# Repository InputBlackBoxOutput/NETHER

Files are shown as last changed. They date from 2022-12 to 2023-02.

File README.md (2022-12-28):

# NETHER
Virtual reality controller for playing minecraft

## Salient features
* Modular to support addons
* Tangle free gaming since the entire system is wireless
* Minimal lag during gaming due to high-speed data transfer
* Product certifications: CE certified and ROHS compliant 

## System block diagram
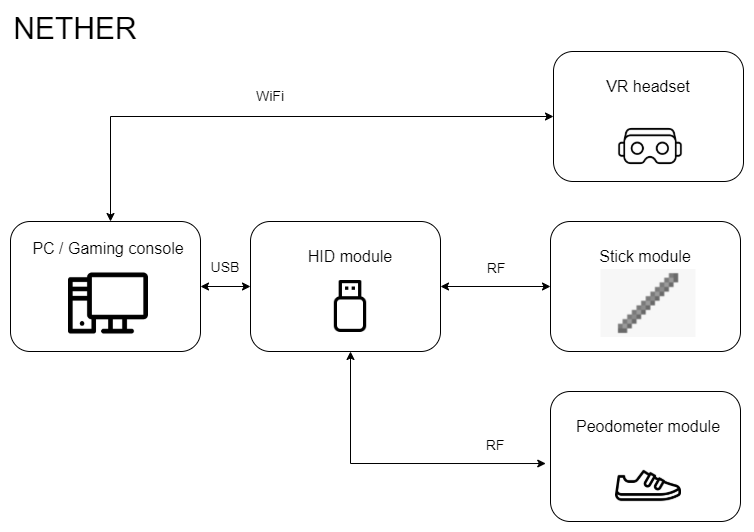
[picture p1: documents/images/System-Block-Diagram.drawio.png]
System block diagram


## HID module

### Functions 
- Act as a wireless gateway between the modules worn by the user and the computer.
- Communicate with the computer via USB as an HID device

### 3D render: Exploded view
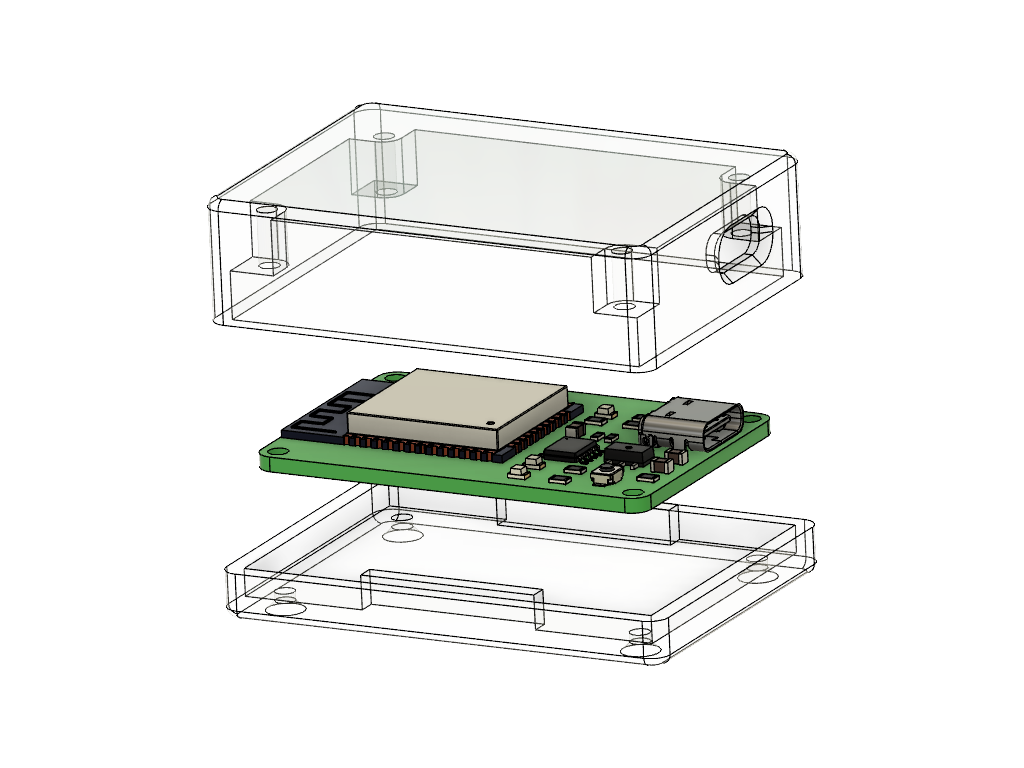
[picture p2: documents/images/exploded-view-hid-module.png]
3D render: Exploded view


## Stick module

### Functions
- Connect with the HID module wirelessly
- Send data associated with a button when a button is pressed
- Read IMU data, detect striking movement and send the data to the HID module
- Calibrate the IMU device when the calibration button is pressed

### 3D render: Exploded view
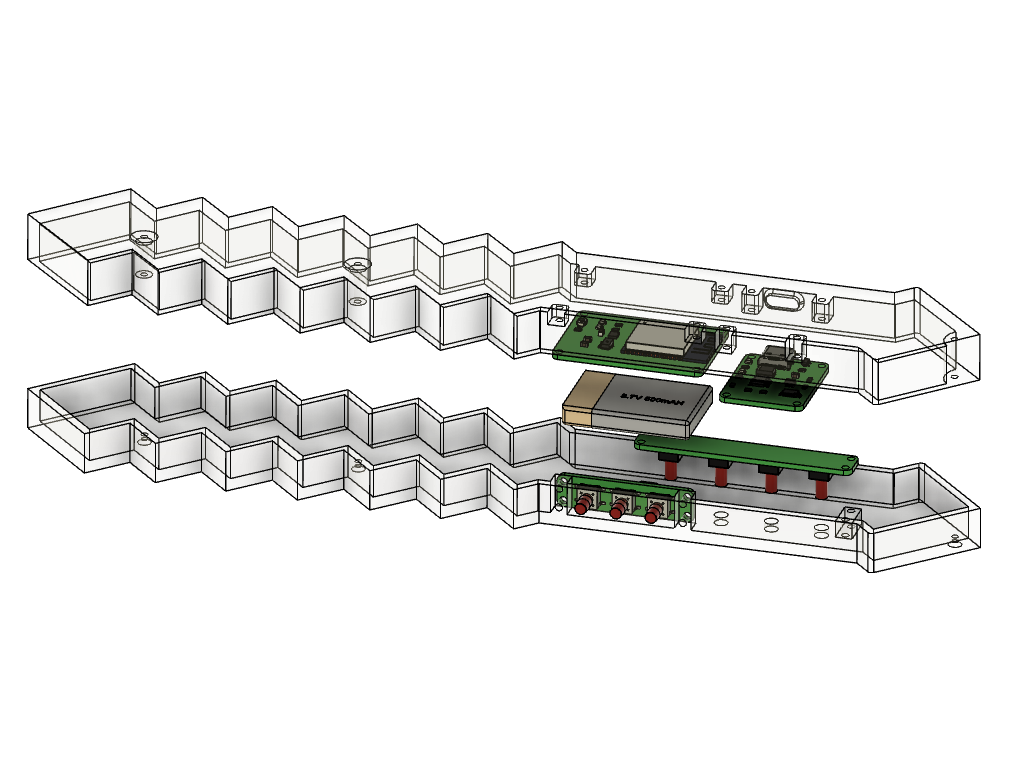
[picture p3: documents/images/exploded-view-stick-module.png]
3D render: Exploded view


## Pedometer module

### Functions
- Connect with the HID module wirelessly
- Read accelerometer data, detect steps and send the data to the HID module
- Calibrate the IMU device when the calibration button is pressed

### 3D render: Exploded view
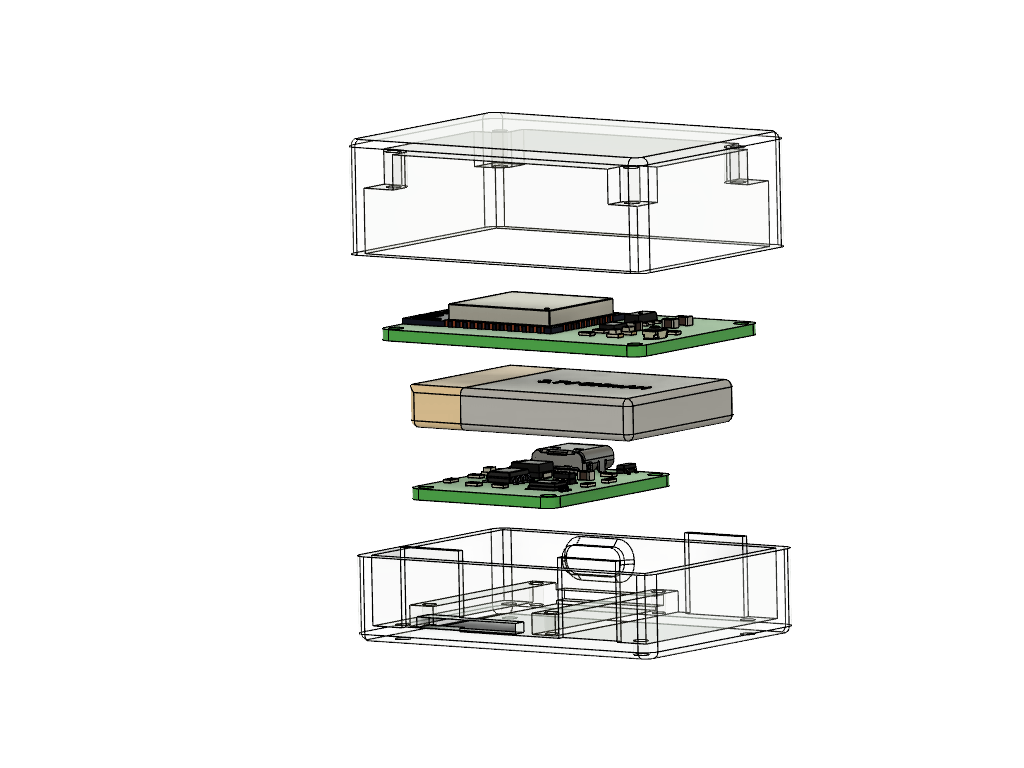
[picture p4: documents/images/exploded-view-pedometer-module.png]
3D render: Exploded view

  
### Made with lots of ⏱️, 📚 and ☕ by InputBlackBoxOutput

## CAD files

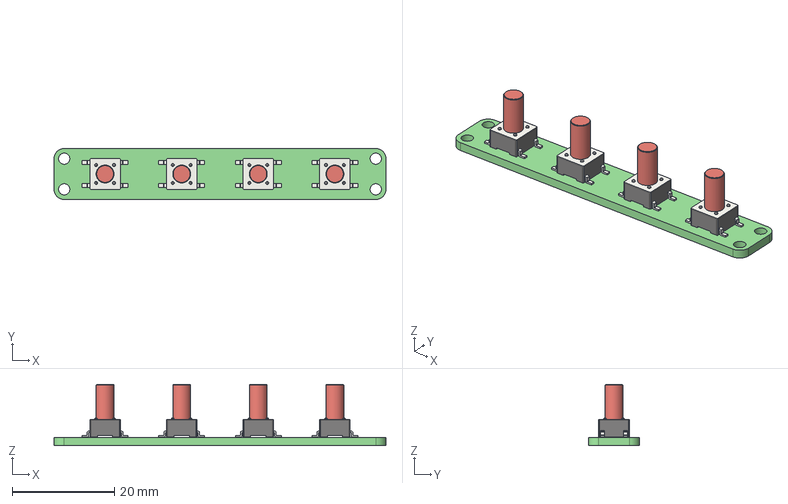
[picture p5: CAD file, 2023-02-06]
modules/Stick module/button-board-1/board.step
65.0 x 10.0 x 12.0 mm

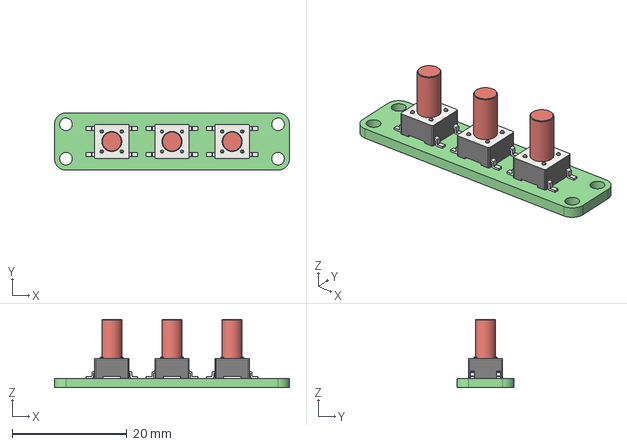
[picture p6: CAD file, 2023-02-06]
modules/Stick module/button-board-2/board.step
41.0 x 10.0 x 12.0 mm

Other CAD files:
modules/HID module/enclosure/Enclosure.f3d
modules/Pedometer module/enclosure/Enclosure.f3d
modules/Stick module/enclosure/Enclosure.f3z

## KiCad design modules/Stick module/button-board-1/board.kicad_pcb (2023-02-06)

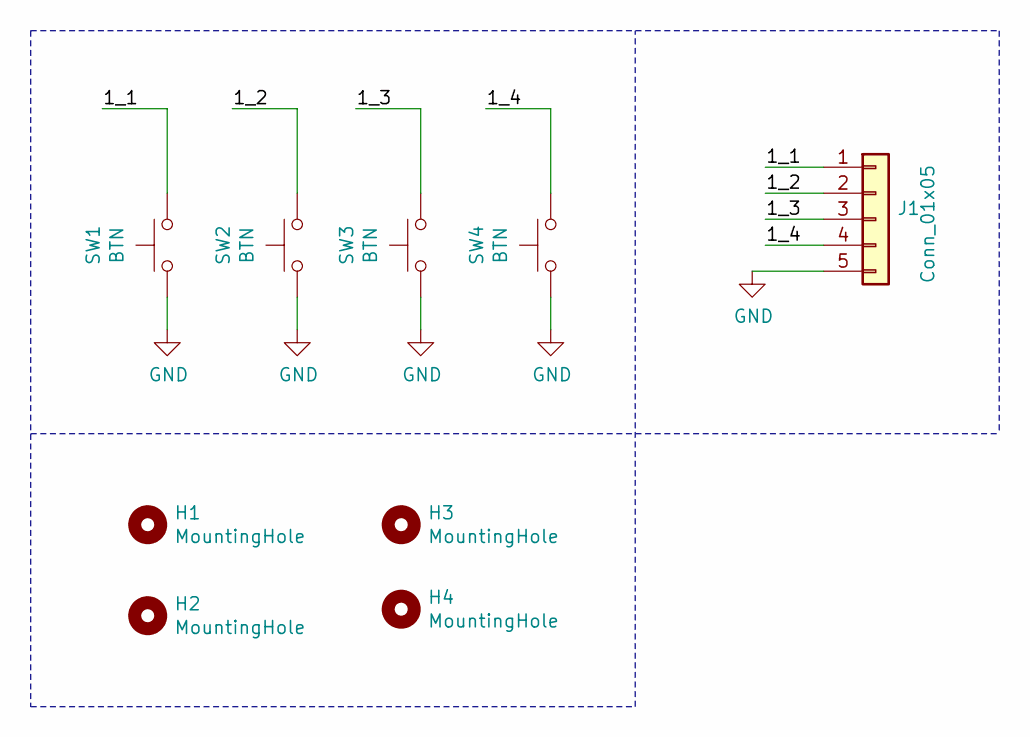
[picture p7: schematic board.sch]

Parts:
H1, H2, H3, H4: MountingHole; MountingHole_2.2mm_M2
J1: Conn_01x05; SolderWire_1x05_P2.54mm
SW1, SW2, SW3, SW4: BTN; SW_SPST_Omron_B3FS-100xP

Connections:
/1_1: J1.1, SW1.2
/1_2: J1.2, SW2.2
/1_3: J1.3, SW3.2
/1_4: J1.4, SW4.2
GND: J1.5, SW1.1, SW2.1, SW3.1, SW4.1

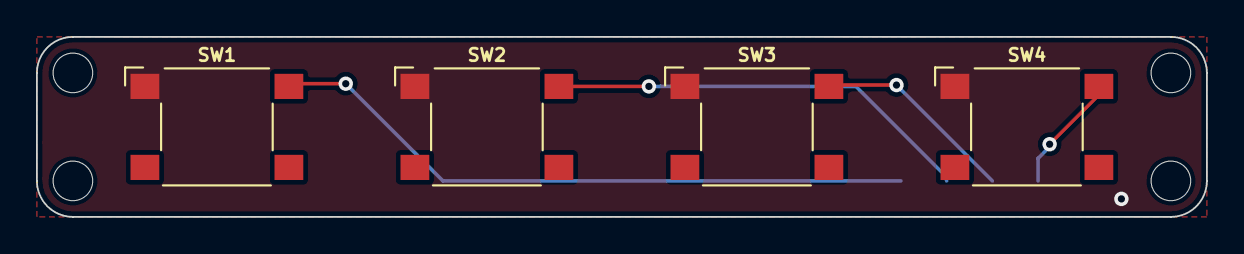
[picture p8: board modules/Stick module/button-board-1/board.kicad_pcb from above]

Board: 2 copper layers, 65.0 x 10.0 mm, 9 parts (1 on the bottom side), 5 nets.

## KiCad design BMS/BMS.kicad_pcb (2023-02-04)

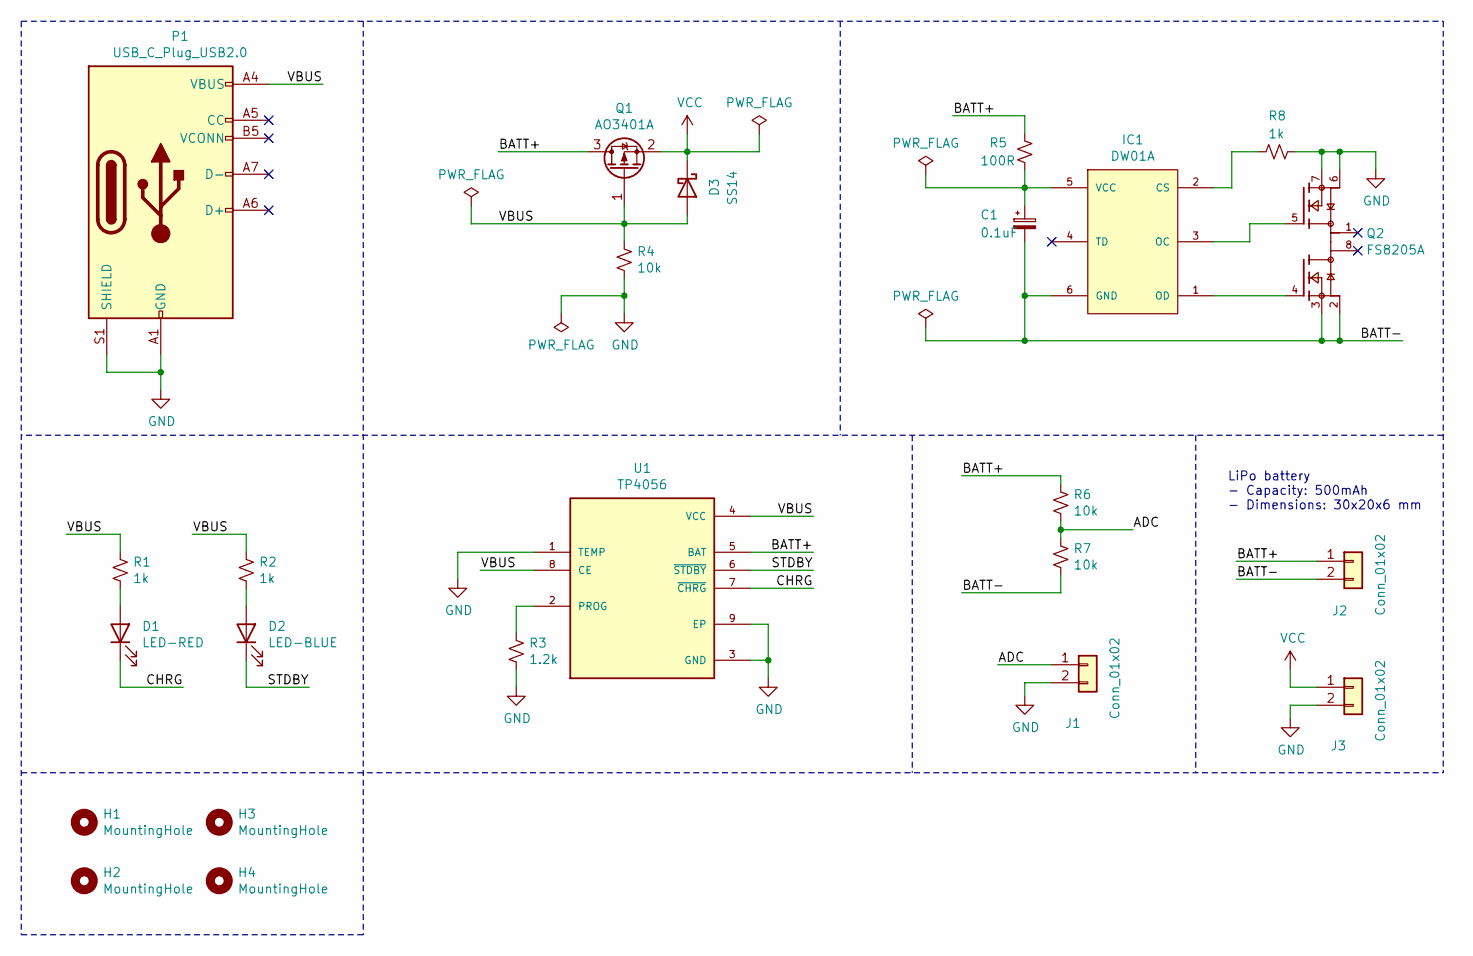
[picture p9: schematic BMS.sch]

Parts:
C1: 0.1uF; C_0805_2012Metric_Pad1.18x1.45mm_HandSolder
D1: LED-RED; LED_0805_2012Metric_Pad1.15x1.40mm_HandSolder
D2: LED-BLUE; LED_0805_2012Metric_Pad1.15x1.40mm_HandSolder
D3: SS14; D_SMB
H1, H2, H3, H4: MountingHole; MountingHole_2.2mm_M2
IC1: DW01A; SOT-23-6_Handsoldering; MPN DW01A; LCSC C351410
J1, J2, J3: Conn_01x02; Wire-Pad-01x02
P1: USB_C_Plug_USB2.0; USB_C_Receptacle_HRO_TYPE-C-31-M-12
Q1: AO3401A; SOT-23
Q2: FS8205A; SOP65P640X120-8N; PARTREV 1.7
R1, R2, R8: 1k; R_0805_2012Metric_Pad1.20x1.40mm_HandSolder
R3: 1.2k; R_0805_2012Metric_Pad1.20x1.40mm_HandSolder
R4, R6, R7: 10k; R_0805_2012Metric_Pad1.20x1.40mm_HandSolder
R5: 100R; R_0805_2012Metric_Pad1.20x1.40mm_HandSolder
U1: TP4056; SOP127P600X175-9N

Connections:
/ADC: J1.1, R6.2, R7.1
/BATT+: J2.1, Q1.3 (D), R5.1, R6.1, U1.5 (BAT)
/BATT-: C1.2, IC1.6 (GND), J2.2, Q2.2, Q2.3, R7.2
/CHRG: D1.1 (K), U1.7 (~CHRG)
/STDBY: D2.1 (K), U1.6 (~STDBY)
/VBUS: D3.2 (A), P1.A4 (VBUS), P1.A9 (VBUS), P1.B4 (VBUS), P1.B9 (VBUS), Q1.1 (G), R1.1, R2.1, R4.1, U1.4 (VCC), U1.8 (CE)
GND: J1.2, J3.2, P1.A1 (GND), P1.A12 (GND), P1.B1 (GND), P1.B12 (GND), P1.S1 (SHIELD), Q2.6, Q2.7, R3.2, R4.2, R8.1, U1.1 (TEMP), U1.3 (GND), U1.9 (EP)
unnamed: C1.1, IC1.5 (VCC), R5.2
unnamed: D1.2 (A), R1.2
unnamed: D2.2 (A), R2.2
unnamed: IC1.1 (OD), Q2.4
unnamed: IC1.2 (CS), R8.2
unnamed: IC1.3 (OC), Q2.5
unnamed: R3.1, U1.2 (PROG)
VCC: D3.1 (K), J3.1, Q1.2 (S)

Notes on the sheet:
LiPo battery - Capacity: 500mAh - Dimensions: 30x20x6 mm

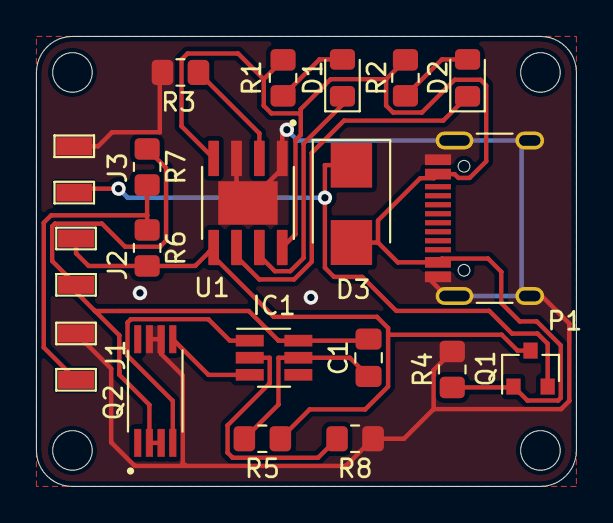
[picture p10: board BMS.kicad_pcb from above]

Board: 2 copper layers, 30.0 x 25.0 mm, 24 parts (0 on the bottom side), 15 nets.

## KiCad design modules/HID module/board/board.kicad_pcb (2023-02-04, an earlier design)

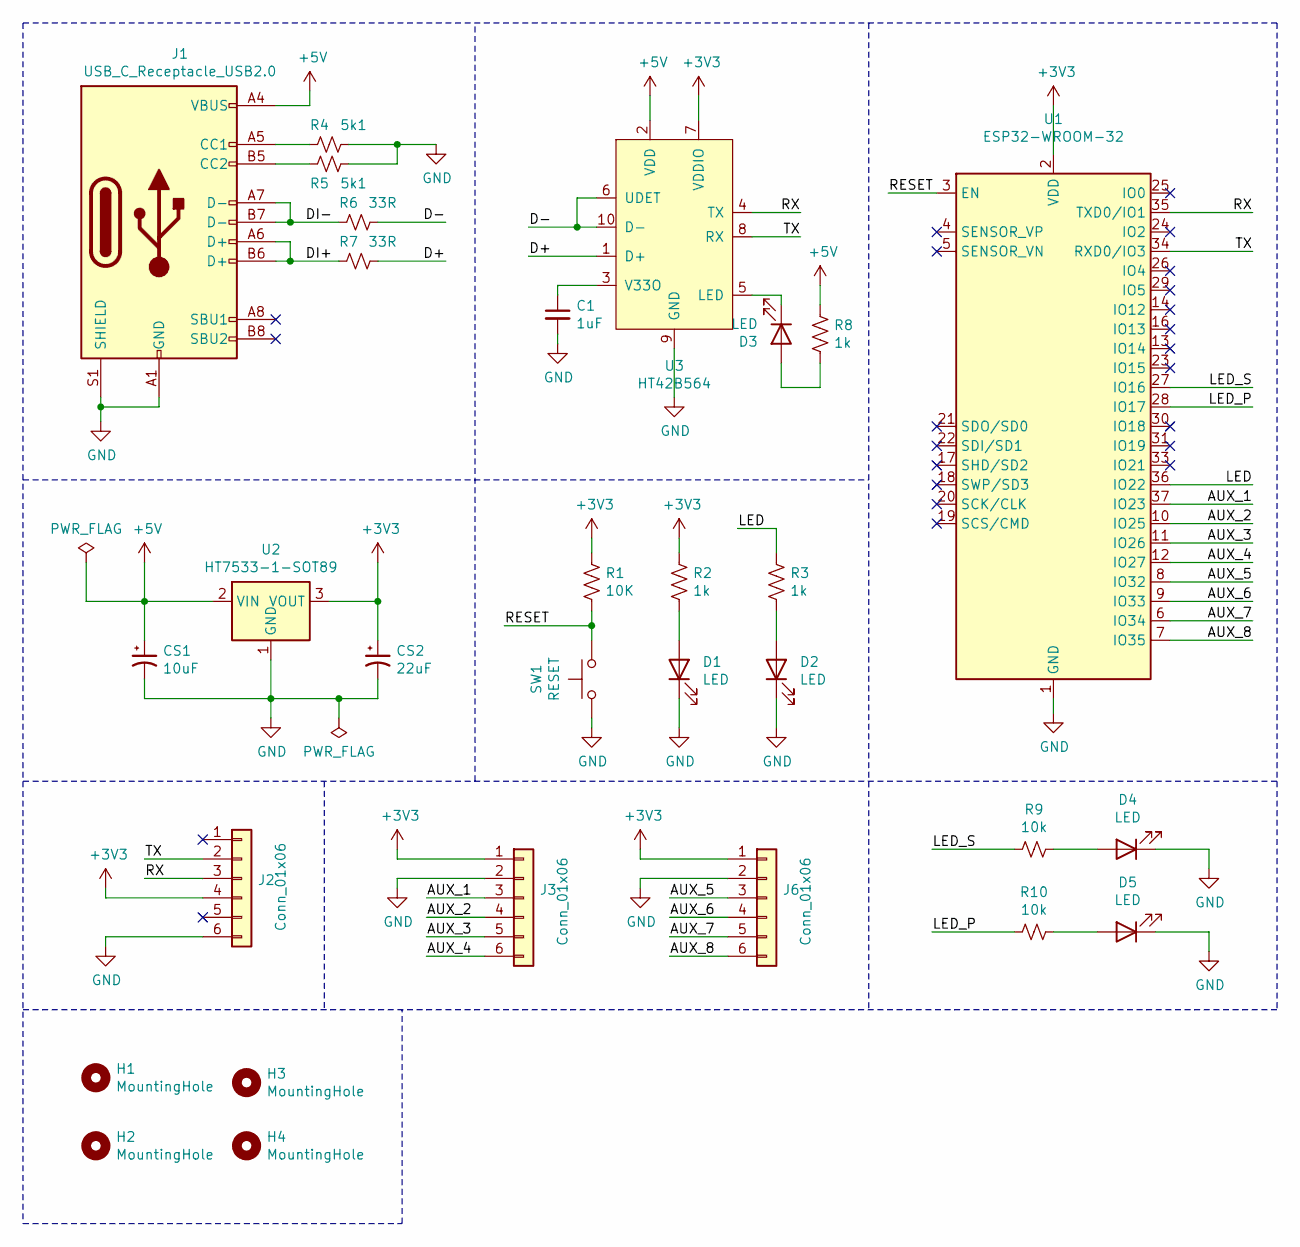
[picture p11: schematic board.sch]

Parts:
C1: 1uF; C_0805_2012Metric_Pad1.18x1.45mm_HandSolder
CS1: 10uF; C_0805_2012Metric_Pad1.18x1.45mm_HandSolder
CS2: 22uF; C_0805_2012Metric_Pad1.18x1.45mm_HandSolder
D1, D2, D3, D4, D5: LED; LED_0805_2012Metric_Pad1.15x1.40mm_HandSolder
H1, H2, H3, H4: MountingHole; MountingHole_2.2mm_M2
J1: USB_C_Receptacle_USB2.0; USB_C_Receptacle_HRO_TYPE-C-31-M-12
J2, J3, J6: Conn_01x06; SolderWire_1x06_P2.54mm
R1: 10K; R_0805_2012Metric_Pad1.20x1.40mm_HandSolder
R2, R3, R8: 1k; R_0805_2012Metric_Pad1.20x1.40mm_HandSolder
R4, R5: 5k1; R_0805_2012Metric_Pad1.20x1.40mm_HandSolder
R6, R7: 33R; R_0603_1608Metric_Pad0.98x0.95mm_HandSolder
R9, R10: 10k; R_0805_2012Metric_Pad1.20x1.40mm_HandSolder
SW1: RESET; SW_SPST_B3U-1000P
U1: ESP32-WROOM-32
U2: HT7533-1-SOT89; SOT-89-3
U3: HT42B564; SSOP-10_3.9x4.9mm_P1.00mm

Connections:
+3V3: CS2.1, J2.4, J3.1, J6.1, R1.1, R2.1, U1.2 (VDD), U2.3 (VOUT), U3.7 (VDDIO)
+5V: CS1.1, J1.A4 (VBUS), J1.A9 (VBUS), J1.B4 (VBUS), J1.B9 (VBUS), R8.1, U2.2 (VIN), U3.2 (VDD)
/AUX_1: J3.3, U1.37 (IO23)
/AUX_2: J3.4, U1.10 (IO25)
/AUX_3: J3.5, U1.11 (IO26)
/AUX_4: J3.6, U1.12 (IO27)
/AUX_5: J6.3, U1.8 (IO32)
/AUX_6: J6.4, U1.9 (IO33)
/AUX_7: J6.5, U1.6 (IO34)
/AUX_8: J6.6, U1.7 (IO35)
/D+: R7.1, U3.1 (D+)
/D-: R6.1, U3.6 (UDET), U3.10 (D-)
/DI+: J1.A6 (D+), J1.B6 (D+), R7.2
/DI-: J1.A7 (D-), J1.B7 (D-), R6.2
/LED: R3.1, U1.36 (IO22)
/LED_P: R10.2, U1.28 (IO17)
/LED_S: R9.2, U1.27 (IO16)
/RESET: R1.2, SW1.2, U1.3 (EN)
/RX: J2.3, U1.35 (TXD0/IO1), U3.4 (TX)
/TX: J2.2, U1.34 (RXD0/IO3), U3.8 (RX)
GND: C1.2, CS1.2, CS2.2, D1.1 (K), D2.1 (K), D4.1 (K), D5.1 (K), J1.A1 (GND), J1.A12 (GND), J1.B1 (GND), J1.B12 (GND), J1.S1 (SHIELD), J2.6, J3.2, J6.2, R4.1, R5.1, SW1.1, U1.1 (GND), U1.15 (GND), U1.38 (GND), U1.39 (GND), U2.1 (GND), U3.9 (GND)
unnamed: C1.1, U3.3 (V33O)
unnamed: D1.2 (A), R2.2
unnamed: D2.2 (A), R3.2
unnamed: D3.1 (K), U3.5 (LED)
unnamed: D3.2 (A), R8.2
unnamed: D4.2 (A), R9.1
unnamed: D5.2 (A), R10.1
unnamed: J1.A5 (CC1), R4.2
unnamed: J1.B5 (CC2), R5.2

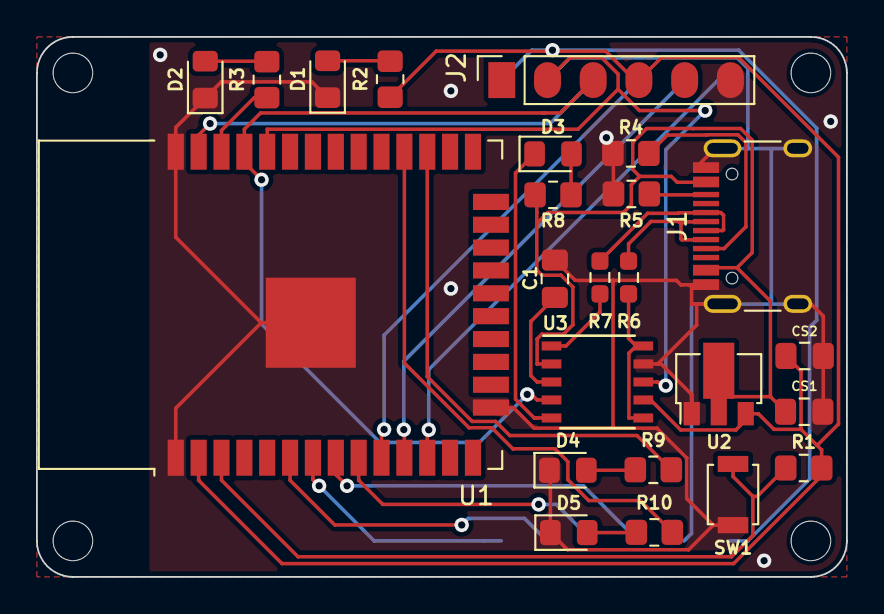
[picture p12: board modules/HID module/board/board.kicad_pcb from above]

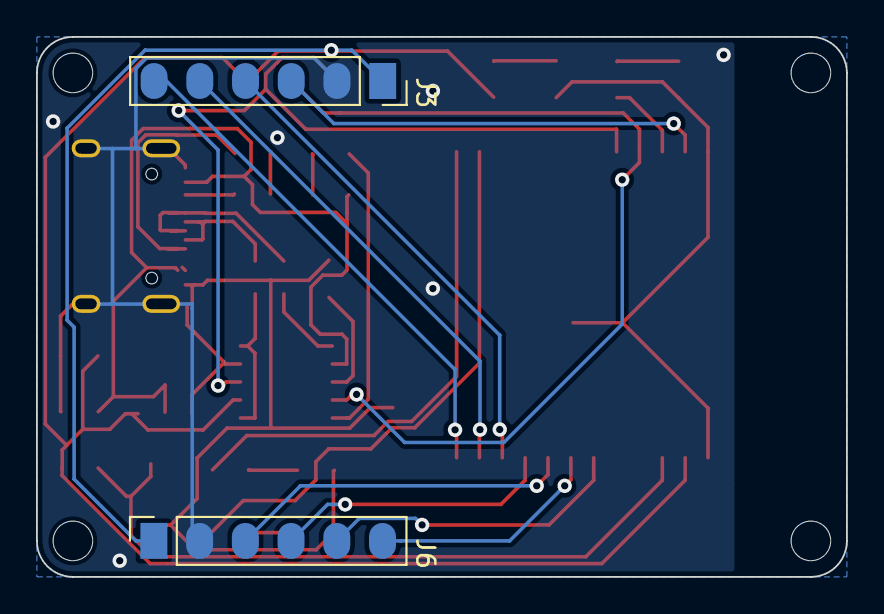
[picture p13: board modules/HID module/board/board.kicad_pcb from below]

Board: 2 copper layers, 45.0 x 30.0 mm, 30 parts (2 on the bottom side), 30 nets.

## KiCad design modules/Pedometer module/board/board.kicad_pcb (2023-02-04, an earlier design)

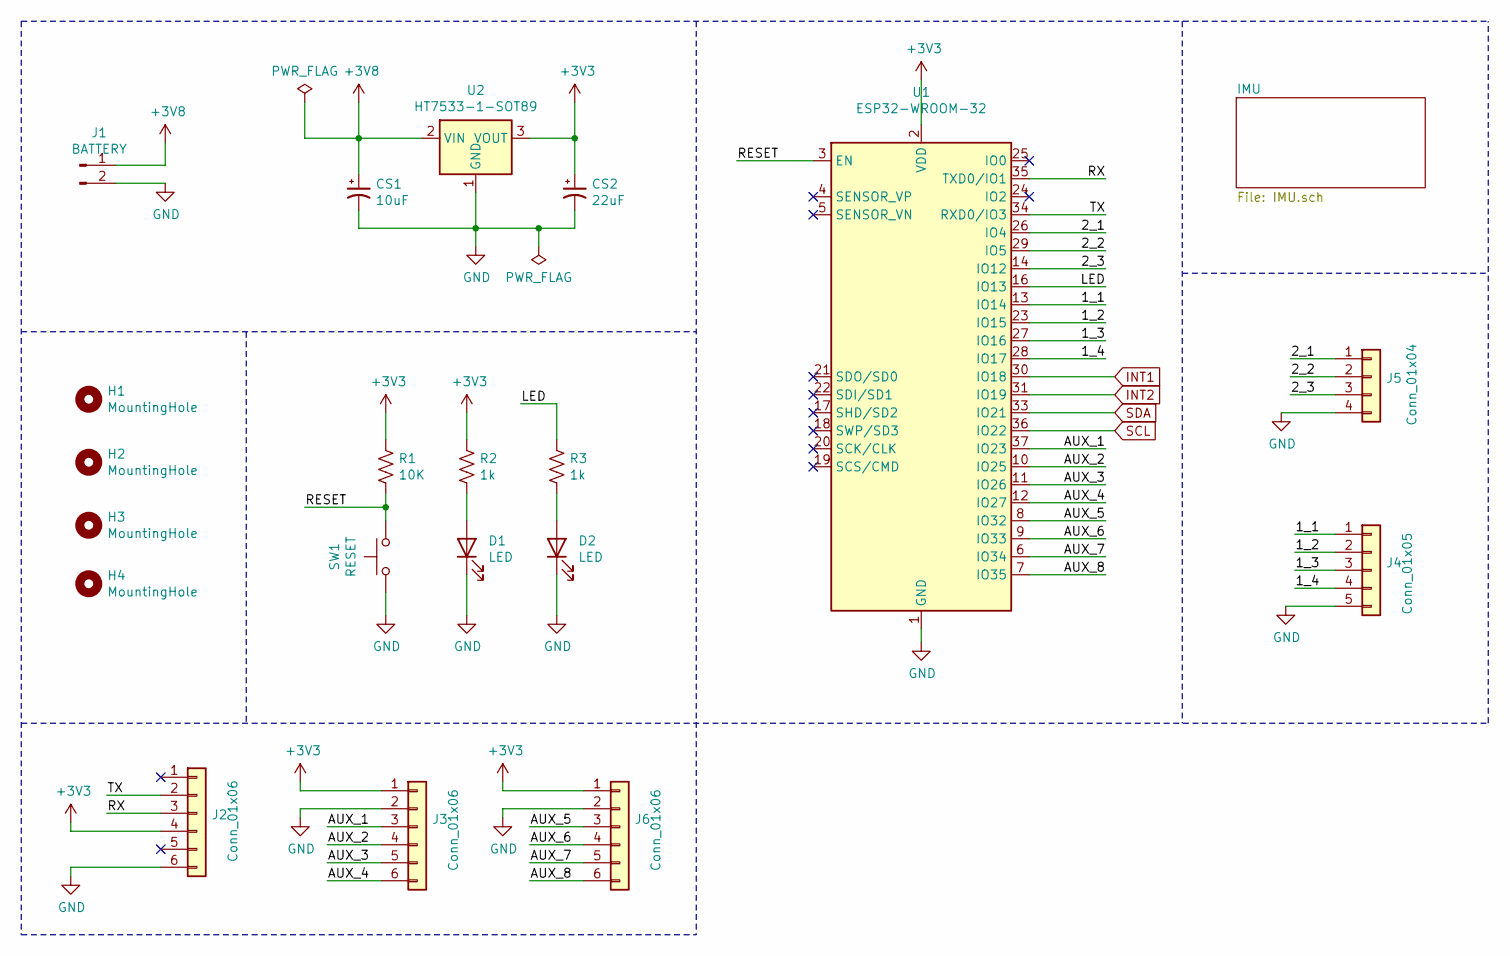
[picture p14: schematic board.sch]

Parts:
CS1: 10uF; C_0805_2012Metric_Pad1.18x1.45mm_HandSolder
CS2: 22uF; C_0805_2012Metric_Pad1.18x1.45mm_HandSolder
D1, D2: LED; LED_0805_2012Metric_Pad1.15x1.40mm_HandSolder
H1, H2, H3, H4: MountingHole; MountingHole_2.2mm_M2
J1: BATTERY; SolderWire_1x02_P2.00mm
J2, J3, J6: Conn_01x06; SolderWire_1x06_P2.54mm
J4: Conn_01x05; SolderWire_1x05_P2.54mm
J5: Conn_01x04; SolderWire_1x04_P2.54mm
R1: 10K; R_0805_2012Metric_Pad1.20x1.40mm_HandSolder
R2, R3: 1k; R_0805_2012Metric_Pad1.20x1.40mm_HandSolder
SW1: RESET; SW_SPST_B3U-1000P
U1: ESP32-WROOM-32
U2: HT7533-1-SOT89; SOT-89-3

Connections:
+3V3: CS2.1, J2.4, J3.1, J6.1, R1.1, R2.1, U1.2 (VDD), U2.3 (VOUT); also elsewhere on the board
+3V8: CS1.1, J1.1, U2.2 (VIN)
/1_1: J4.1, U1.13 (IO14)
/1_2: J4.2, U1.23 (IO15)
/1_3: J4.3, U1.27 (IO16)
/1_4: J4.4, U1.28 (IO17)
/2_1: J5.1, U1.26 (IO4)
/2_2: J5.2, U1.29 (IO5)
/2_3: J5.3, U1.14 (IO12)
/AUX_1: J3.3, U1.37 (IO23)
/AUX_2: J3.4, U1.10 (IO25)
/AUX_3: J3.5, U1.11 (IO26)
/AUX_4: J3.6, U1.12 (IO27)
/AUX_5: J6.3, U1.8 (IO32)
/AUX_6: J6.4, U1.9 (IO33)
/AUX_7: J6.5, U1.6 (IO34)
/AUX_8: J6.6, U1.7 (IO35)
/LED: R3.1, U1.16 (IO13)
/RESET: R1.2, SW1.2, U1.3 (EN)
/RX: J2.3, U1.35 (TXD0/IO1)
/TX: J2.2, U1.34 (RXD0/IO3)
GND: CS1.2, CS2.2, D1.1 (K), D2.1 (K), J1.2, J2.6, J3.2, J4.5, J5.4, J6.2, SW1.1, U1.1 (GND), U1.15 (GND), U1.38 (GND), U1.39 (GND), U2.1 (GND); also elsewhere on the board
INT1: U1.30 (IO18); also elsewhere on the board
INT2: U1.31 (IO19); also elsewhere on the board
unnamed: D1.2 (A), R2.2
unnamed: D2.2 (A), R3.2
SCL: U1.36 (IO22); also elsewhere on the board
SDA: U1.33 (IO21); also elsewhere on the board

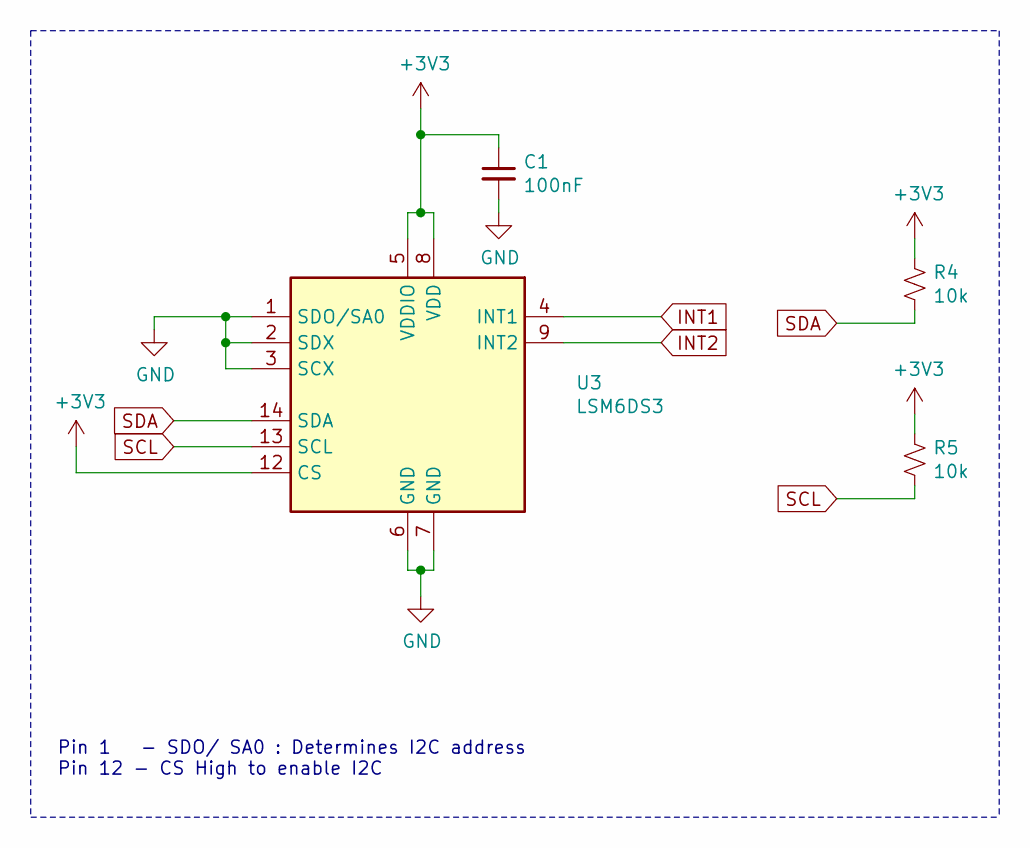
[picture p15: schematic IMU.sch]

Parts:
C1: 100nF; C_0805_2012Metric_Pad1.18x1.45mm_HandSolder
R4, R5: 10k; R_0805_2012Metric_Pad1.20x1.40mm_HandSolder
U3: LSM6DS3; LGA-14_3x2.5mm_P0.5mm_LayoutBorder3x4y

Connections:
+3V3: C1.1, R4.1, R5.1, U3.5 (VDDIO), U3.8 (VDD), U3.12 (CS); also elsewhere on the board
GND: C1.2, U3.1 (SDO/SA0), U3.2 (SDX), U3.3 (SCX), U3.6 (GND), U3.7 (GND); also elsewhere on the board
INT1: U3.4 (INT1); also elsewhere on the board
INT2: U3.9 (INT2); also elsewhere on the board
SCL: R5.2, U3.13 (SCL); also elsewhere on the board
SDA: R4.2, U3.14 (SDA); also elsewhere on the board

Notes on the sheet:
Pin 1 - SDO/ SA0 : Determines I2C address Pin 12 - CS High to enable I2C

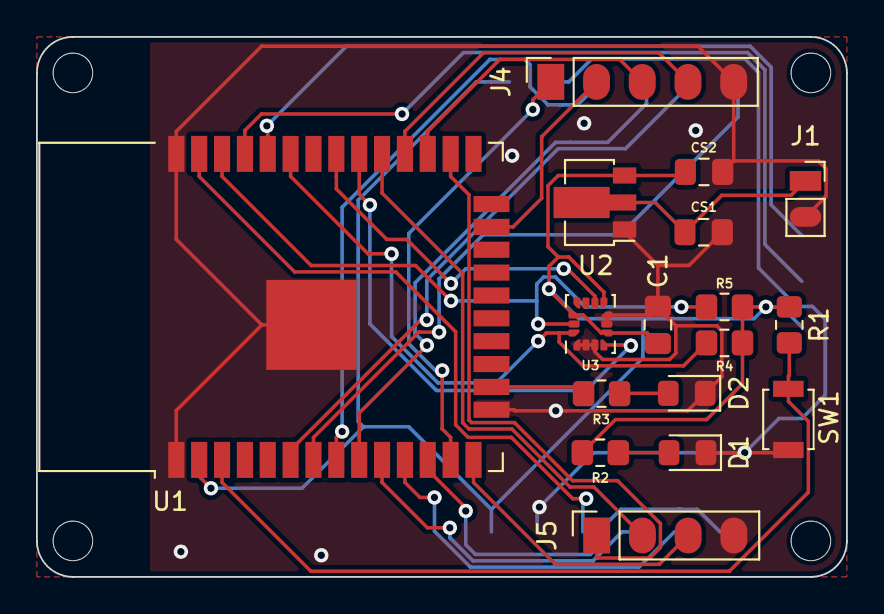
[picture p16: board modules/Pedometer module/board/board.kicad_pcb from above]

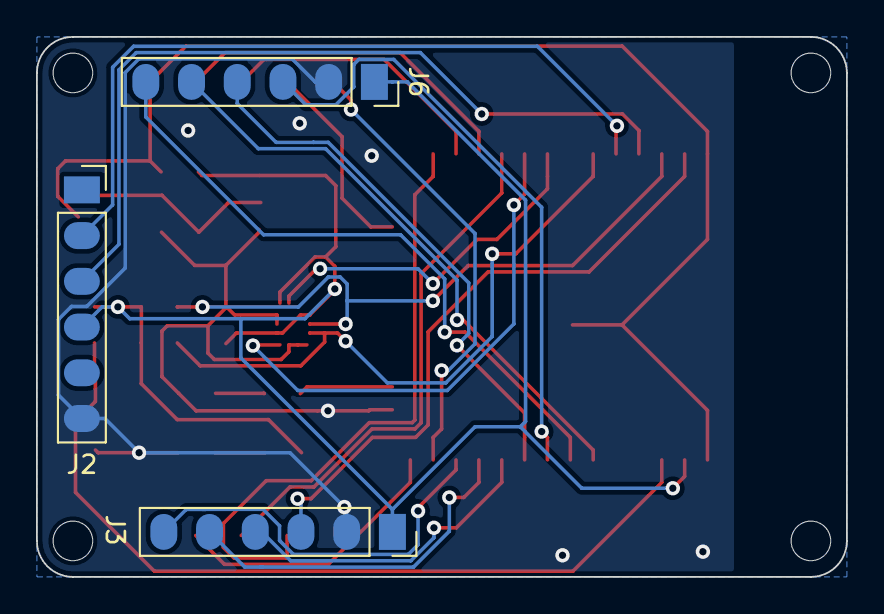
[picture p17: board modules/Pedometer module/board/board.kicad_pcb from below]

Board: 2 copper layers, 45.0 x 30.0 mm, 24 parts (3 on the bottom side), 28 nets.

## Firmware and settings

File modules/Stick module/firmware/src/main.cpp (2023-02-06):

// Stick module firmware
//
// TODO:
// TinyML based action classifier: Strike & Place
// Use buttons to implement other in-game actions
//
// References:
// https://randomnerdtutorials.com/esp-now-many-to-one-esp32/
// https://randomnerdtutorials.com/get-change-esp32-esp8266-mac-address-arduino/
// https://docs.arduino.cc/learn/communication/wire

#include <Arduino.h>
#include "connections.h"
#include "IMU.h"
#include <WiFi.h>
#include <esp_now.h>

#define LOOP_DELAY 100 //ms
#define DEBOUNCE_DELAY 20 //us

uint8_t broadcastAddress[] = {0x32, 0xAE, 0xA4, 0x07, 0x0D, 0x66};

typedef struct struct_payload
{
  uint8_t id;
  char action;
} struct_payload;

struct_payload payload;
esp_now_peer_info_t peerInfo;

void OnDataSent(const uint8_t *mac_addr, esp_now_send_status_t status)
{
  Serial.print("\r\nLast Packet Send Status:\t");
  Serial.println(status == ESP_NOW_SEND_SUCCESS ? 1 : 0);
}

LSM6DSM IMU = LSM6DSM();

bool buttonPressed(uint8_t btn) {
  if(!digitalRead(btn)) {
    delayMicroseconds(DEBOUNCE_DELAY);
    if(!digitalRead(btn)) {
      return true;
    }
  }

  return false;
}

void setup()
{
  // Setup serial port for debugging purposes
  Serial.begin(115200);
  Serial.println();

  // Setup GPIO pins
  pinMode(LED, OUTPUT);

  pinMode(BTN_11, INPUT_PULLUP);
  pinMode(BTN_12, INPUT_PULLUP);
  pinMode(BTN_13, INPUT_PULLUP);
  pinMode(BTN_14, INPUT_PULLUP);

  pinMode(BTN_21, INPUT_PULLUP);
  pinMode(BTN_22, INPUT_PULLUP);
  pinMode(BTN_23, INPUT_PULLUP);

  // Setup IMU LSM6DSM
  if (!IMU.checkID())
  {
    Serial.println("Unable to connect to connect to LSM6DSM");
  }

  // Setup ESP-NOW
  WiFi.mode(WIFI_STA);

  if (esp_now_init() != ESP_OK)
  {
    Serial.println("Error initializing ESP-NOW");
    return;
  }

  esp_now_register_send_cb(OnDataSent);

  // Connect with ESP-NOW peer
  memcpy(peerInfo.peer_addr, broadcastAddress, 6);
  peerInfo.channel = 0;
  peerInfo.encrypt = false;

  if (esp_now_add_peer(&peerInfo) != ESP_OK)
  {
    Serial.println("Failed to add peer");
    return;
  }
}

void loop()
{
  IMU.readDataAccelerometer();
  IMU.readDataGyroscope();
  float magnitude;

  // Action: Break block
  magnitude = sqrt(IMU.accel_x * IMU.accel_x + 0.15 * IMU.accel_y * IMU.accel_y + 0.15 * IMU.accel_z * IMU.accel_z);
  if (magnitude >= 65536.0f) {
    payload.id = 0;
    payload.action = 'S';

    esp_err_t result = esp_now_send(broadcastAddress, (uint8_t *)&payload, sizeof(payload));

    if (result != ESP_OK)
      Serial.println("Error sending data via ESP-NOW");
  }

  // Action: Place block
  magnitude = sqrt(0.15 * IMU.accel_x * IMU.accel_x + 0.15 * IMU.accel_y * IMU.accel_y + IMU.accel_z * IMU.accel_z);
  if (magnitude >= 65536.0f)
  {
    payload.id = 0;
    payload.action = 'P';

    esp_err_t result = esp_now_send(broadcastAddress, (uint8_t *)&payload, sizeof(payload));

    if (result != ESP_OK)
      Serial.println("Error sending data via ESP-NOW");
  }

  // if (buttonPressed(BTN_X)) {
  //   payload.id = 0;
  //   payload.action = 'X';

  //   esp_err_t result = esp_now_send(broadcastAddress, (uint8_t *)&payload, sizeof(payload));

  //   if (result != ESP_OK)
  //     Serial.println("Error sending data via ESP-NOW");
  // }

  delay(LOOP_DELAY);
}

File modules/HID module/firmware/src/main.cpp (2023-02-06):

// HID module firmware
//
// TODO:
// USB HID keyboard and mouse implementation
// Map actions to in game keystrokes
//
// References:
// https://randomnerdtutorials.com/esp-now-many-to-one-esp32/
// https://randomnerdtutorials.com/get-change-esp32-esp8266-mac-address-arduino/

#include <Arduino.h>
#include "connections.h"
#include <WiFi.h>
#include <esp_now.h>
#include <esp_wifi.h>

uint8_t MACAddress[] = {0x32, 0xAE, 0xA4, 0x07, 0x0D, 0x66};

typedef struct struct_payload
{
  uint8_t id;
  char action;
} struct_payload;

struct_payload payload;

void setupMACAddress()
{
  Serial.print("[OLD] ESP32 Board MAC Address:  ");
  Serial.println(WiFi.macAddress());

  esp_wifi_set_mac(WIFI_IF_STA, &MACAddress[0]);

  Serial.print("[NEW] ESP32 Board MAC Address:  ");
  Serial.println(WiFi.macAddress());
}

void OnDataRecieved(const uint8_t *mac_addr, const uint8_t *incomingPayload, int len)
{
  memcpy(&payload, incomingPayload, sizeof(payload));

  Serial.printf("Module: %c \n", payload.id);
  Serial.println();
  Serial.printf("Action: %c \n", payload.action);
  Serial.println();

  switch(payload.action) {
    // Action: Break block
    case 'S':
      // HID.sendMouseClick("LEFT");
      break;
    
    // Action: Place block
    case 'P':
      // HID.sendMouseClick("RIGHT");
      break;
    
    // Action: Move forward
    case 'W':
      // HID.sendKeystroke("UP_ARROW");
      break;
  }
}

void setup()
{
  // Setup serial port for debugging purposes
  Serial.begin(9600);

  // Setup GPIO pins
  pinMode(LED_S, OUTPUT);
  pinMode(LED_P, OUTPUT);
  pinMode(LED, OUTPUT);

  // Change MAC address for easy programmability
  setupMACAddress();

  // Setup ESP-NOW
  WiFi.mode(WIFI_STA);

  if (esp_now_init() != ESP_OK)
  {
    Serial.println("Error initializing ESP-NOW");
    return;
  }

  esp_now_register_recv_cb(OnDataRecieved);
}

void loop()
{
}

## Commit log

2022-12-21 BMS design files added
    [BMS.dsn, BMS.kicad_pcb, BMS.sch]
2022-12-25 Stick module: PCB design files added
    [IMU.sch, board.dsn, board.kicad_pcb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]
2022-12-25 Pedometer module: PCB design files added
    [IMU.sch, board.dsn, board.kicad_pcb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]
2022-12-26 HID module: PCB design files added
    [IMU.sch, board.dsn, board.kicad_pcb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]
2022-12-31 Fix I2C pullup resistor
    [IMU.sch, board.dsn, board.kicad_pcb]
2023-01-02 Enclosure design files
    [Enclosure.f3d, Enclosure.f3z]
2023-02-04 PCB: USB C receptacle moved close to PCB edge
    [BMS.kicad_pcb, board.kicad_pcb, board.sch]
2023-02-06 Stick module: Button PCB
    [Enclosure.f3z, board.dsn, board.kicad_pcb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]
